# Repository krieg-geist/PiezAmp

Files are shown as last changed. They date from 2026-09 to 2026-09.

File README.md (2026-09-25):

# PiezAmp

Piezos straight into pedals sound like deep fried ass, so I built this preamp. 
There's like 1000 of these circuits, but I wanted an all in one solution that you could just throw in
a noisebox and have it sound halfway decent, with some tweaks to really dial in a nice sound.

Based on Richard Mudhar's
[low-noise piezo preamp](http://www.richardmudhar.com/blog/piezo-contact-microphone-hi-z-amplifier-low-noise-version/),
doubled up and extended. 

## Features

- **1 MΩ inputs.** Piezo discs have waaaay too high impedance for line inputs.
  At 1 MΩ they keep their full THICCNESS (results may vary with piezo guitar pickups, 
  this is mainly designed for cheap discs).
- **Gain:** ×2 to ×12 (+6 to +21.6 dB) per channel.
- **Low noise:** about −119 dBu with a 15 nF disc, inshallah.
- **Blend** between channel A and channel B.
- **Phase invert.** This might help when you have two piezos in the same box so 
  they don't phase cancel eachother out
- **High-cut  filter** from about 27 kHz down to about 34 Hz.
- **Master volume** with a 9 mm panel pot. It shoooould (?) mount in line with the output
  jack.
- **Mono or stereo output** on a TRS jack. Using it in stereo mode bypasses the
  volume and filter. I mainly did this to use with digital drum triggers, so for a basic
  noisebox setup you probably want mono.
- **Power:** 9–18 V DC, should work with a 9v battery, or with pretty much any barreljack
  adapter you have lying around.

## How it works

- Read [Richard Mudhar's blog](http://www.richardmudhar.com/blog/piezo-contact-microphone-hi-z-amplifier-low-noise-version/) lol

## Connections

| Ref | Header / part | Pin 1 | Pin 2 | Pin 3 |
|---|---|---|---|---|
| J5 | Piezo A in | signal | GND | |
| J6 | Piezo B in | signal | GND | |
| J4 | Power in | +9–18 V | GND | |
| SW1 | Power switch (in series with +V) | from J4 | to board | |
| RV5 | Master volume (9 mm right-angle pot) | GND | wiper (out) | top |
| J3 | Output, 6.35 mm TRS | tip = mono / A | ring = B (stereo) | sleeve = GND |

The inputs are 2-pin headers. You can put jacks on em or just wire the piezos directly
to the inputs. Polarity shouldn't matter.

If you don't want an on/off switch, just connect the switch terminal with a piece of wire or something

## Controls

| Control | Function |
|---|---|
| Gain A / gain B | ×2 - ×12 gain,CW = more gain |
| Blend | A <-> B |
| High-cut | 27 kHz -> 34 Hz, CW = more cut |
| Master volume | CW = louder |

**DIP switch SW2** (set with the power off):

| Pos | Function | Mono | Stereo |
|---|---|---|---|
| 1 | Channel B polarity invert | either | either |
| 2 | A direct to the output buffer | OFF | ON |
| 3 | Volume bypass | OFF | ON |
| 4 | B to the ring | OFF | ON |

- **Mono:** blend -> high-cut -> volume -> tip. A TS or TRS lead works.
- **Stereo:** A -> tip, B -> ring, with no blend, filter or volume. Use a TRS
  lead.

**Setting up:** Make a loud noise, and raise each
gain until the output is just below clipping. Try flip DIP 1: whichever setting sounds nicer is
right. Then set the blend, the high-cut and the master to taste.

## Customisation

- **Trimmers to panel pots.** Any trimmer (RV1–RV4) can be replaced by a panel
  pot wired to its three pads:
  - Pot lug 1 -> pad 1, wiper -> pad 2, lug 3 -> pad 3. The board already ties
    pads 2 and 3 where the circuit needs a variable resistor.
  - Use the same resistance value as the trimmer. The exception is RV3, where
    anything from 5k to 10k works.
  - **For the high-cut (RV4), a log 1 MΩ pot is best.** It spreads
    the sweep evenly, where a linear part crams everything above 4 kHz into
    the first few degrees of rotation (sorry).
- **Jumpering trimmers to fixed settings.** Leave the trimmer out and link or
  fit parts instead:
  - **Gain, fixed:** link pads 1–2 for minimum gain (×2). For any other fixed
    gain, fit a resistor R across pads 1–2: gain = 2 + R / 1 kΩ.
  - **Blend, fixed:** link pads 2–1 for A only, or pads 2–3 for B only. For an
    equal mix, fit two equal resistors (about 2.2k), one from pad 1 to pad 2
    and one from pad 3 to pad 2.
  - **High-cut, off:** link pads 1–2. The filter is then fully open.
  - **High-cut, fixed:** fit a resistor R across pads 1–2: fc ≈ 1 / (2π · R · 4.7 nF).
    For example, 33k gives about 1 kHz.
  - **Master volume:** RV5's holes also take a 1×3 pin header for an off-board
    pot. For fixed full volume, link pads 2–3 (the same as DIP 3).
- **More headroom:** run it on 18 V. Shouldn't catch fire.

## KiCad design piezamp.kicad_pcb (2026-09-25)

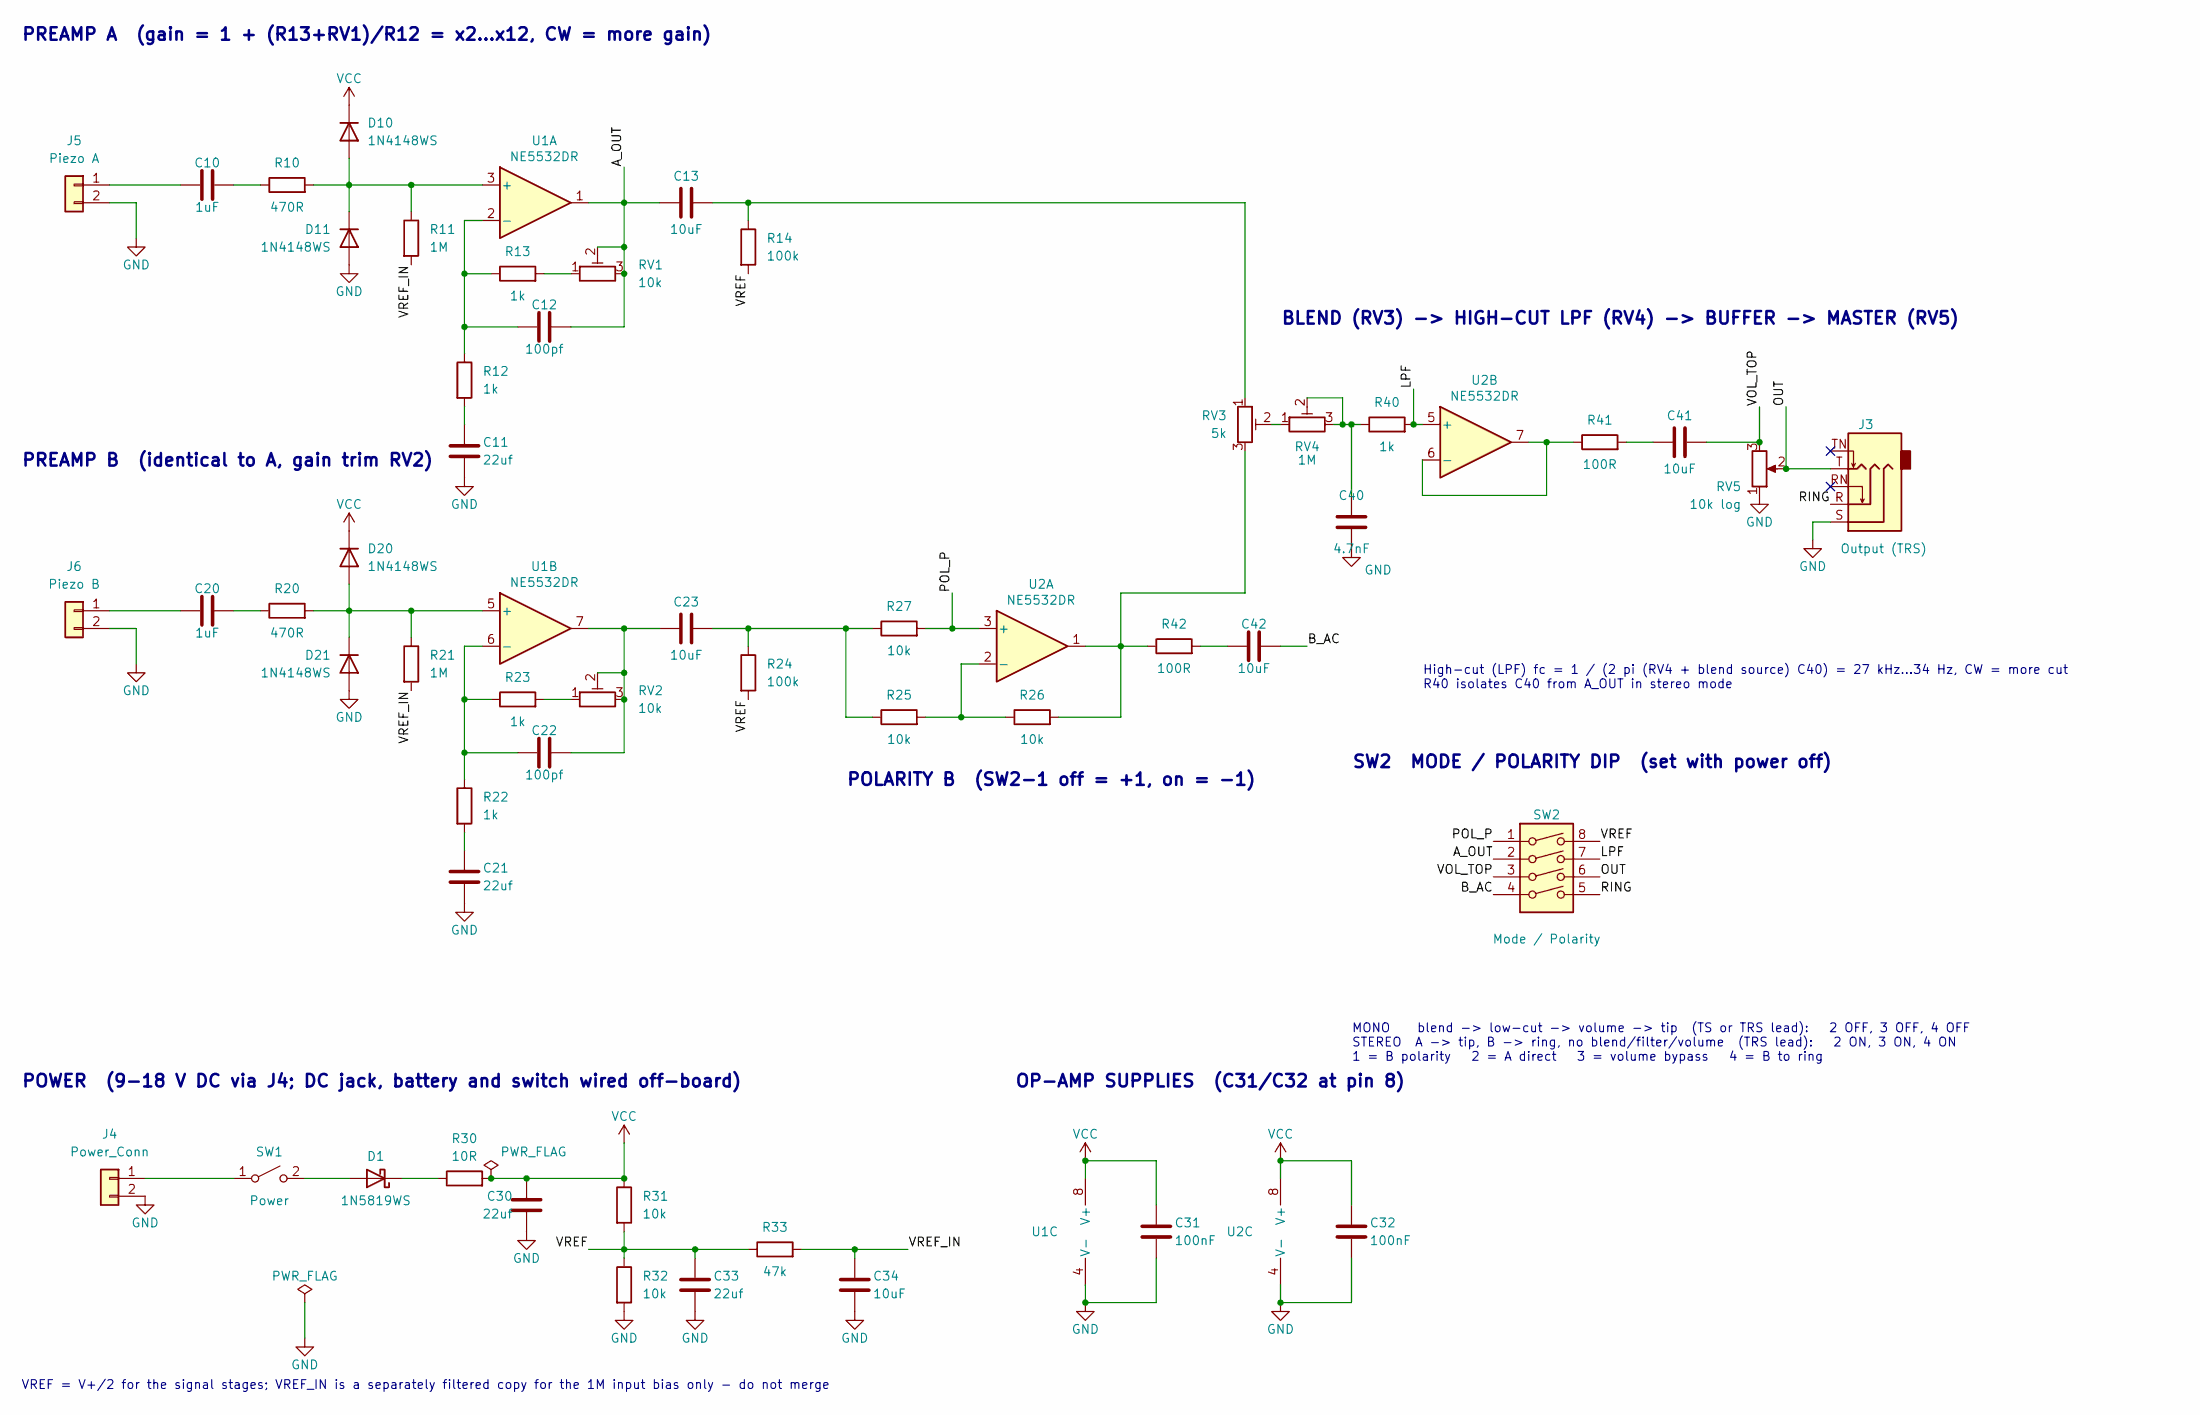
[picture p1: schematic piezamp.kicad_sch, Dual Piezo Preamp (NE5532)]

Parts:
C10, C20: 1uF; C_0805_2012Metric
C11, C21, C30, C33: 22uf; C_1206_3216Metric
C12, C22: 100pf; C_0603_1608Metric
C13, C23, C34, C41, C42: 10uF; C_0805_2012Metric
C31, C32: 100nF; C_0603_1608Metric
C40: 4.7nF; C_0805_2012Metric
D1: 1N5819WS; D_SOD-123
D10, D11, D20, D21: 1N4148WS; D_SOD-323
J3: Output (TRS); Jack_6.35mm_Neutrik_NMJ6HCD2_Horizontal
J4: Power_Conn; PinHeader_1x02_P2.54mm_Vertical
J5: Piezo A; PinHeader_1x02_P2.54mm_Vertical
J6: Piezo B; PinHeader_1x02_P2.54mm_Vertical
R10, R20: 470R; R_0603_1608Metric
R11, R21: 1M; R_0603_1608Metric
R12, R13, R22, R23, R40: 1k; R_0603_1608Metric
R14, R24: 100k; R_0603_1608Metric
R25, R26, R27, R31, R32: 10k; R_0603_1608Metric
R30: 10R; R_0603_1608Metric
R33: 47k; R_0603_1608Metric
R41, R42: 100R; R_0603_1608Metric
RV1, RV2: 10k; Potentiometer_Runtron_RM-065_Vertical
RV3: 5k; Potentiometer_Runtron_RM-065_Vertical
RV4: 1M; Potentiometer_Runtron_RM-065_Vertical
RV5: 10k log; Potentiometer_Alps_RK09K_Single_Horizontal
SW1: Power; PinHeader_1x02_P2.54mm_Vertical
SW2: Mode / Polarity; SW_DIP_SPSTx04_Slide_9.78x12.34mm_W7.62mm_P2.54mm
U1, U2: NE5532DR; SOIC-8_3.9x4.9mm_P1.27mm

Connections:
/A_OUT: C12.2, C13.2, RV1.2, RV1.3, SW2.2, U1.1
/B_AC: C42.2, SW2.4
/LPF: R40.2, SW2.7, U2.5 (+)
/OUT: J3.T, RV5.2, SW2.6
/POL_P: R27.2, SW2.1, U2.3 (+)
/RING: J3.R, SW2.5
/VOL_TOP: C41.2, RV5.3, SW2.3
/VREF: C33.1, R14.2, R24.2, R31.2, R32.1, R33.1, SW2.8
/VREF_IN: C34.1, R11.2, R21.2, R33.2
GND: C11.2, C21.2, C30.2, C31.2, C32.2, C33.2, C34.2, C40.2, D11.2 (A), D21.2 (A), J3.S, J4.2, J5.2, J6.2, R32.2, RV5.1, U1.4 (V-), U2.4 (V-)
unnamed: C10.2, R10.1
unnamed: C11.1, R12.2
unnamed: C13.1, R14.1, RV3.1
unnamed: C20.2, R20.1
unnamed: C21.1, R22.2
unnamed: C22.2, C23.2, RV2.2, RV2.3, U1.7
unnamed: C23.1, R24.1, R25.1, R27.1
unnamed: C40.1, R40.1, RV4.2, RV4.3
unnamed: C41.1, R41.2
unnamed: C42.1, R42.2
unnamed: D1.2 (A), SW1.2 (B)
unnamed: D1.1 (K), R30.1
unnamed: D10.2 (A), D11.1 (K), R10.2, R11.1, U1.3 (+)
unnamed: D20.2 (A), D21.1 (K), R20.2, R21.1, U1.5 (+)
unnamed: J4.1, SW1.1 (A)
unnamed: C10.1, J5.1
unnamed: C20.1, J6.1
unnamed: R13.2, RV1.1
unnamed: R23.2, RV2.1
unnamed: R26.2, R42.1, RV3.3, U2.1
unnamed: RV3.2, RV4.1
unnamed: C12.1, R12.1, R13.1, U1.2 (-)
unnamed: C22.1, R22.1, R23.1, U1.6 (-)
unnamed: R25.2, R26.1, U2.2 (-)
unnamed: R41.1, U2.6 (-), U2.7
VCC: C30.1, C31.1, C32.1, D10.1 (K), D20.1 (K), R30.2, R31.1, U1.8 (V+), U2.8 (V+)

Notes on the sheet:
High-cut (LPF) fc = 1 / (2 pi (RV4 + blend source) C40) = 27 kHz...34 Hz, CW = more cut R40 isolates C40 from A_OUT in stereo mode
POWER (9-18 V DC via J4; DC jack, battery and switch wired off-board)
BLEND (RV3) -> HIGH-CUT LPF (RV4) -> BUFFER -> MASTER (RV5)
PREAMP B (identical to A, gain trim RV2)
POLARITY B (SW2-1 off = +1, on = -1)
VREF = V+/2 for the signal stages; VREF_IN is a separately filtered copy for the 1M input bias only - do not merge
SW2 MODE / POLARITY DIP (set with power off)
OP-AMP SUPPLIES (C31/C32 at pin 8)
MONO blend -> low-cut -> volume -> tip (TS or TRS lead): 2 OFF, 3 OFF, 4 OFF STEREO A -> tip, B -> ring, no blend/filter/volume (TRS lead): 2 ON, 3 ON, 4 ON 1 = B polarity 2 = A direct 3 = volume bypass 4 = B to ring
PREAMP A (gain = 1 + (R13+RV1)/R12 = x2...x12, CW = more gain)

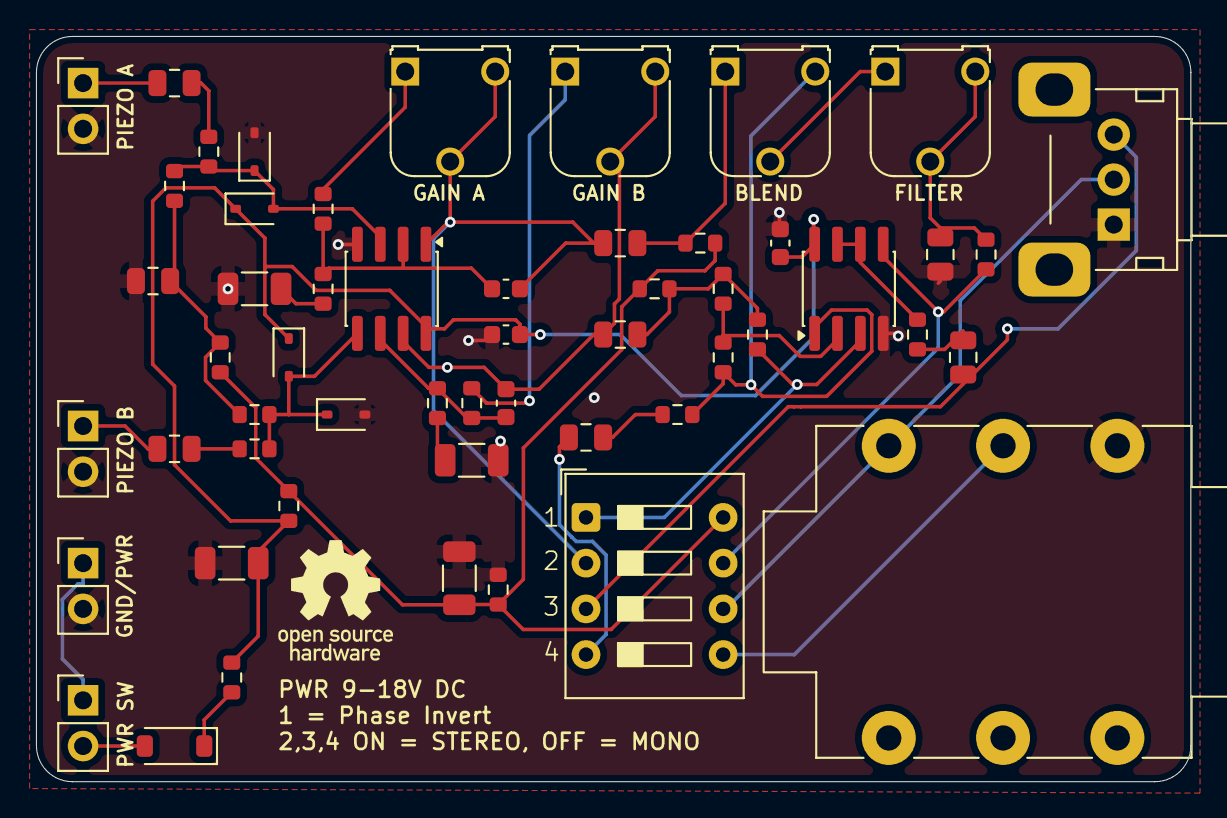
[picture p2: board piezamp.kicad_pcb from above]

Board: 2 copper layers, 64.1 x 41.4 mm, 54 parts (0 on the bottom side), 36 nets.

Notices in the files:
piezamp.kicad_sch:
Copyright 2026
